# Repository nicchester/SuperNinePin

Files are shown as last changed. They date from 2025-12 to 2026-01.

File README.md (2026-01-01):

# SuperNinePin Controller Adaptor

Converts a Super Nintendo controller to an Amiga/Commodore 64 controller, using digital logic. (none of this microcontroller nonsense)

### Why do such a thing? 

It's easy to throw a microcontroller at everything, and it ocurred to me I haven't done much useful in pure digital logic with the lowest possible IC count. So this is just for the fun of doing it, and also it's quite a fitting project for a 'vintage' use case. 

---

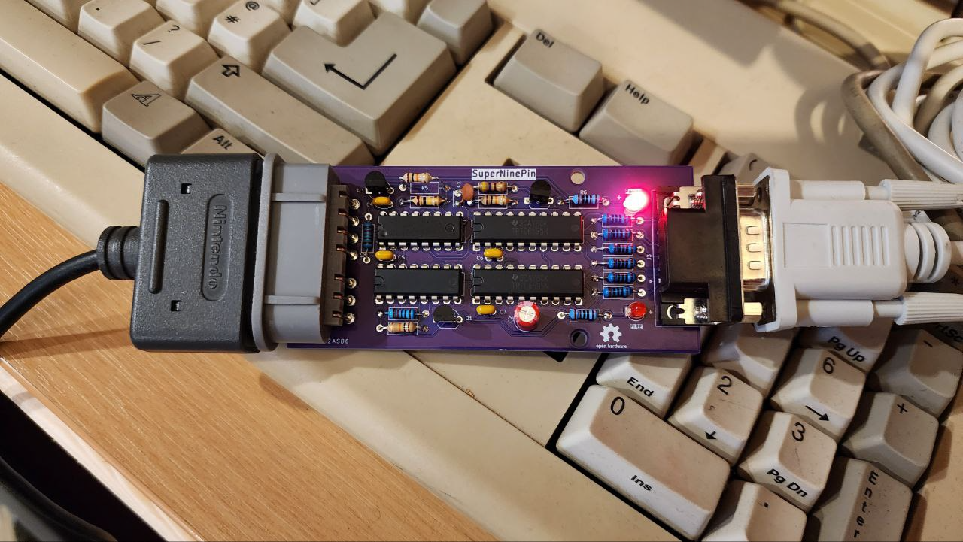
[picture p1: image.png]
The SuperNinePin hooked up to my Amiga 2000


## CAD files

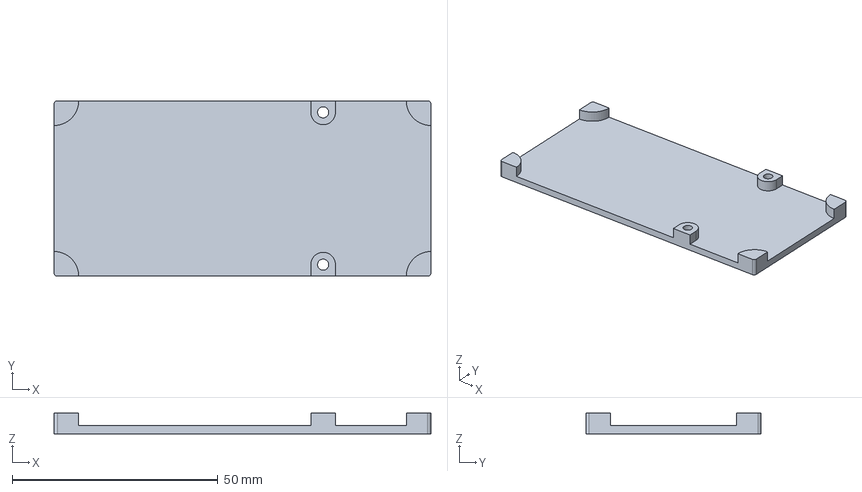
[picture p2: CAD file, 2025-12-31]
Sled/Sled.FCStd
91.6 x 42.6 x 5.00 mm

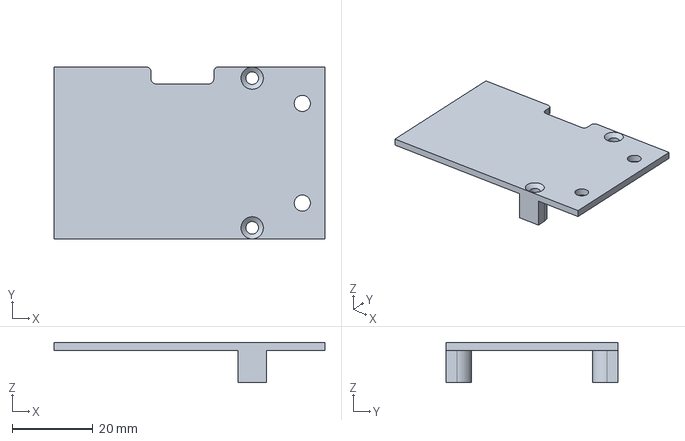
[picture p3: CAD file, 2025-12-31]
Sled/Lid.FCStd
67.0 x 42.6 x 10.0 mm

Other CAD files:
Sled/Lid.stl
Sled/Sled.stl

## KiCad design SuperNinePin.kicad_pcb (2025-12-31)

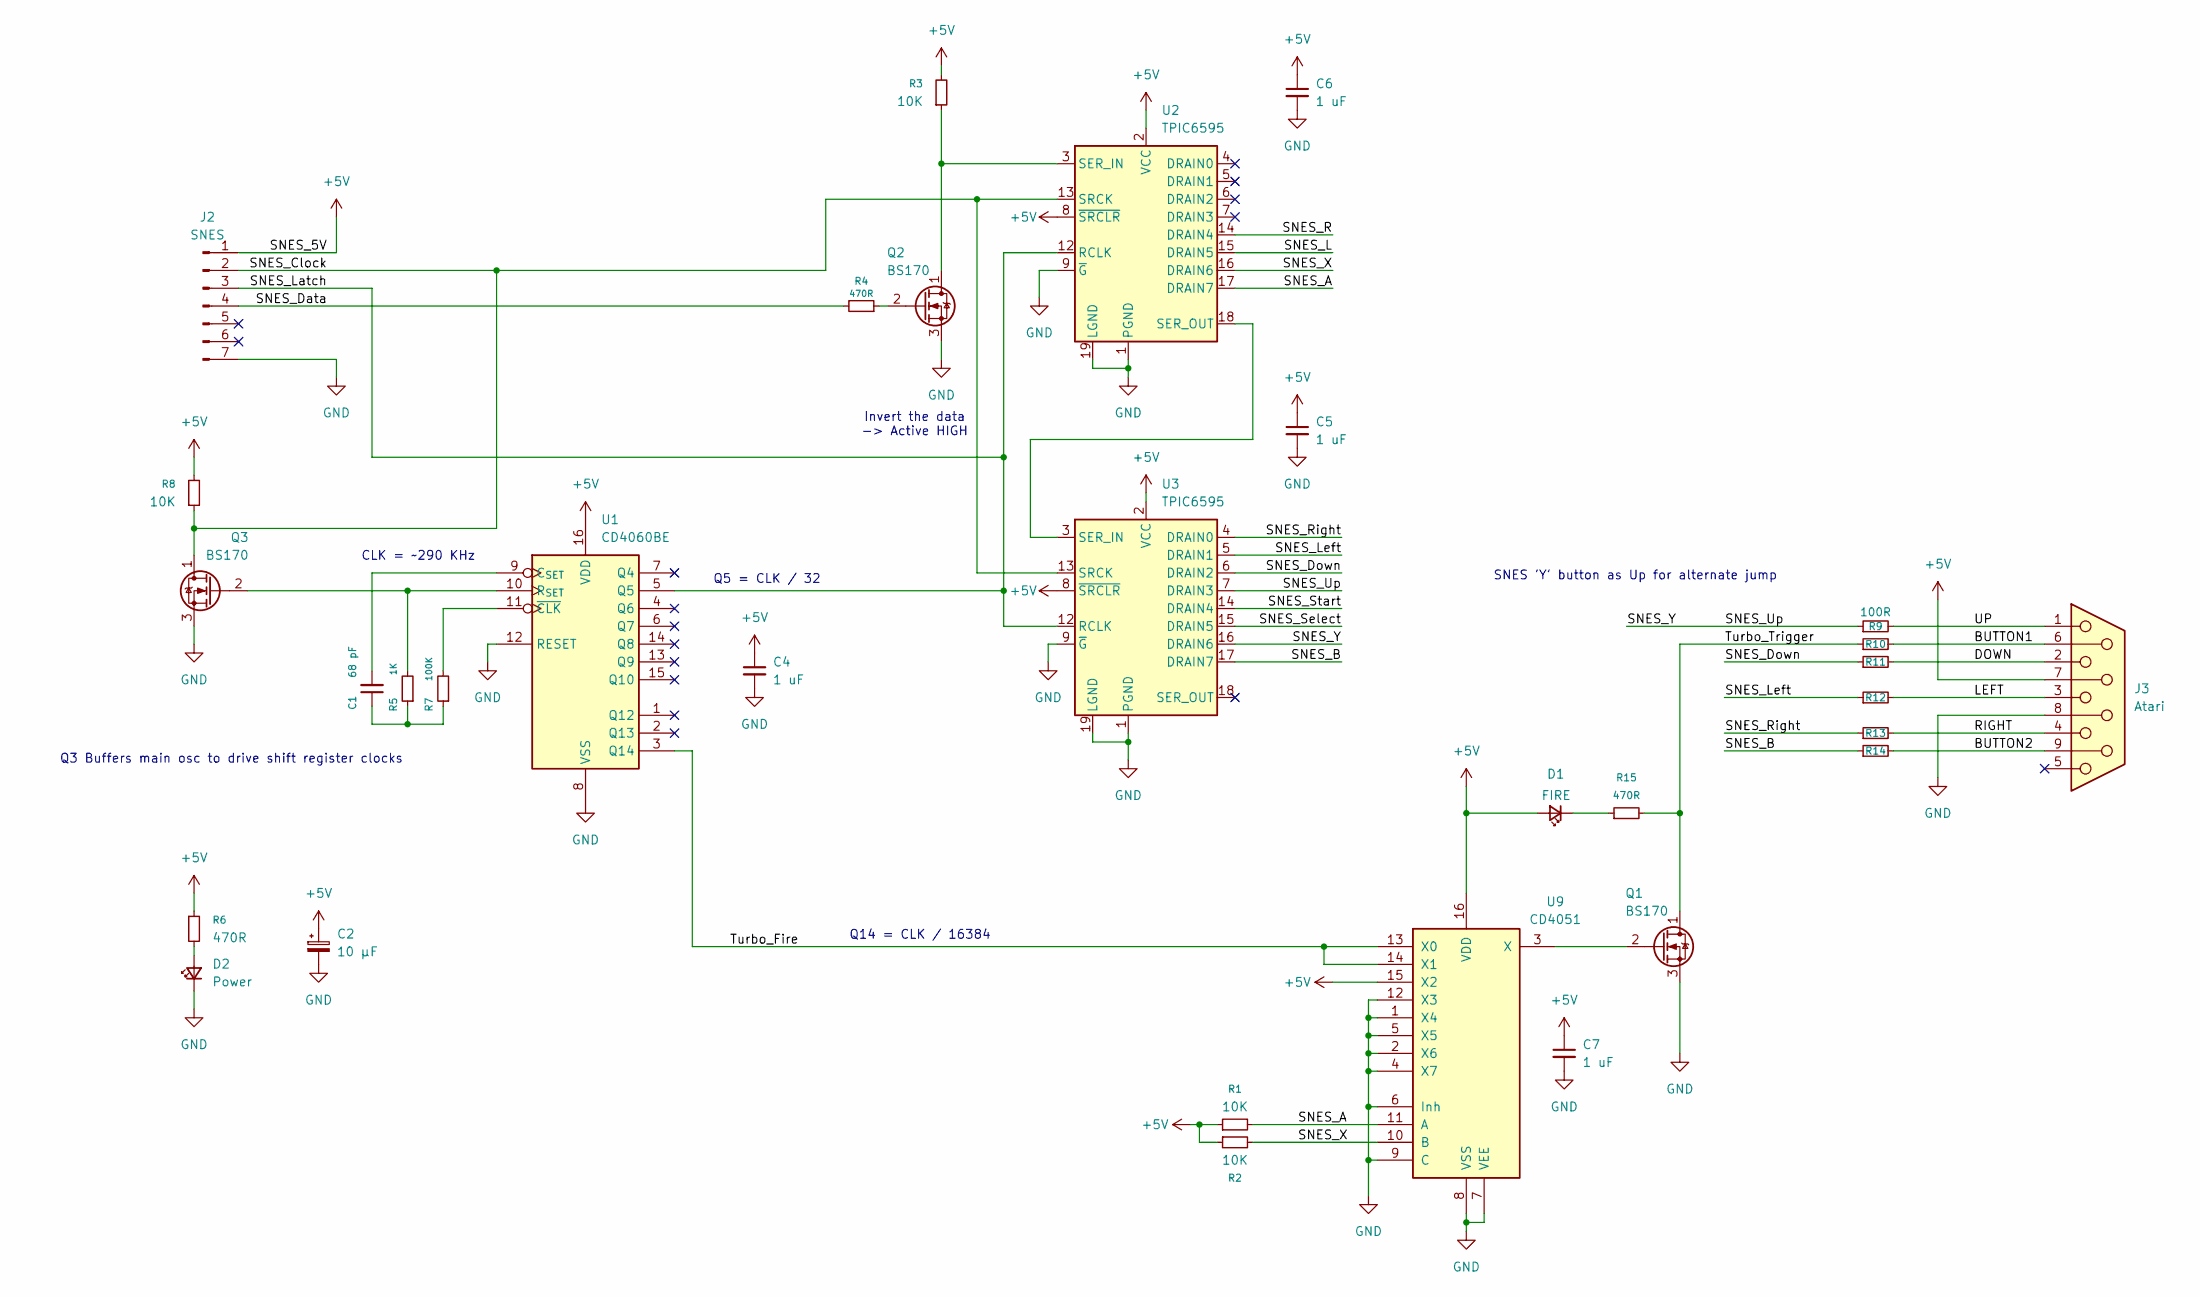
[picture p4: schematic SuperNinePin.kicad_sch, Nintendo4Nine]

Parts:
C1: 68 pF; C_Disc_D3.4mm_W2.1mm_P2.50mm
C2: 10 µF; C_Radial_D5.0mm_H5.0mm_P2.00mm
C4, C5, C6, C7: 1 uF; C_Disc_D3.0mm_W1.6mm_P2.50mm
D1: FIRE; LED_D3.0mm
D2: Power; LED_D3.0mm
J2: SNES; SNESController
J3: Atari; DSUB-9_Pins_Horizontal_P2.77x2.84mm_EdgePinOffset4.94mm_Hou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
Q1, Q2, Q3: BS170; TO-92_Inline_Wide
R1, R2, R3, R8: 10K; R_Axial_DIN0207_L6.3mm_D2.5mm_P10.16mm_Horizontal
R4, R6, R15: 470R; R_Axial_DIN0207_L6.3mm_D2.5mm_P10.16mm_Horizontal
R5: 1K; R_Axial_DIN0207_L6.3mm_D2.5mm_P10.16mm_Horizontal
R7: 100K; R_Axial_DIN0207_L6.3mm_D2.5mm_P10.16mm_Horizontal
R9, R10, R11, R12, R13, R14: 100R; R_Axial_DIN0207_L6.3mm_D2.5mm_P10.16mm_Horizontal
U1: CD4060BE; DIP-16_W7.62mm
U2, U3: TPIC6595; DIP-20_W7.62mm
U9: CD4051; DIP-16_W7.62mm

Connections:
+5V: C2.1, C4.1, C5.1, C6.1, C7.1, D1.2 (A), J2.1, J3.7, R1.1, R2.1, R3.2, R6.1, R8.2, U1.16 (VDD), U2.2 (VCC), U2.8 (~SRCLR), U3.2 (VCC), U3.8 (~SRCLR), U9.15 (X2), U9.16 (VDD)
/BUTTON1: J3.6, R10.2
/BUTTON2: J3.9, R14.2
/DOWN: J3.2, R11.2
/LEFT: J3.3, R12.2
/RIGHT: J3.4, R13.2
/SNES_A: R1.2, U2.17 (DRAIN7), U9.11 (A)
/SNES_B: R14.1, U3.17 (DRAIN7)
/SNES_Clock: J2.2, Q3.1 (D), R8.1, U2.13 (SRCK), U3.13 (SRCK)
/SNES_Data: J2.4, R4.2
/SNES_Down: R11.1, U3.6 (DRAIN2)
/SNES_L: U2.15 (DRAIN5)
/SNES_Latch: J2.3, U1.5 (Q5), U2.12 (RCLK), U3.12 (RCLK)
/SNES_Left: R12.1, U3.5 (DRAIN1)
/SNES_R: U2.14 (DRAIN4)
/SNES_Right: R13.1, U3.4 (DRAIN0)
/SNES_Select: U3.15 (DRAIN5)
/SNES_Start: U3.14 (DRAIN4)
/SNES_Up: R9.1, U3.7 (DRAIN3), U3.16 (DRAIN6)
/SNES_X: R2.2, U2.16 (DRAIN6), U9.10 (B)
/Turbo_Fire: U1.3 (Q14), U9.13 (X0), U9.14 (X1)
/Turbo_Trigger: Q1.1 (D), R10.1, R15.2
/UP: J3.1, R9.2
GND: C2.2, C4.2, C5.2, C6.2, C7.2, D2.1 (K), J2.7, J3.8, Q1.3 (S), Q2.3 (S), Q3.3 (S), U1.8 (VSS), U1.12 (RESET), U2.1 (PGND), U2.9 (~G), U2.10 (PGND), U2.11 (PGND), U2.19 (LGND), U2.20 (PGND), U3.1 (PGND), U3.9 (~G), U3.10 (PGND), U3.11 (PGND), U3.19 (LGND), U3.20 (PGND), U9.1 (X4), U9.2 (X6), U9.4 (X7), U9.5 (X5), U9.6 (Inh), U9.7 (VEE), U9.8 (VSS), U9.9 (C), U9.12 (X3)
unnamed: C1.1, R5.1, R7.1
unnamed: D1.1 (K), R15.1
unnamed: D2.2 (A), R6.2
unnamed: Q1.2 (G), U9.3 (X)
unnamed: Q2.1 (D), R3.1, U2.3 (SER_IN)
unnamed: Q2.2 (G), R4.1
unnamed: Q3.2 (G), R5.2, U1.10 (R_{SET})
unnamed: C1.2, U1.9 (C_{SET})
unnamed: R7.2, U1.11 (~CLK)
unnamed: U2.18 (SER_OUT), U3.3 (SER_IN)

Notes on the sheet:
Q14 = CLK / 16384
SNES 'Y' button as Up for alternate jump
Invert the data -> Active HIGH
Q5 = CLK / 32
Q3 Buffers main osc to drive shift register clocks
CLK = ~290 KHz

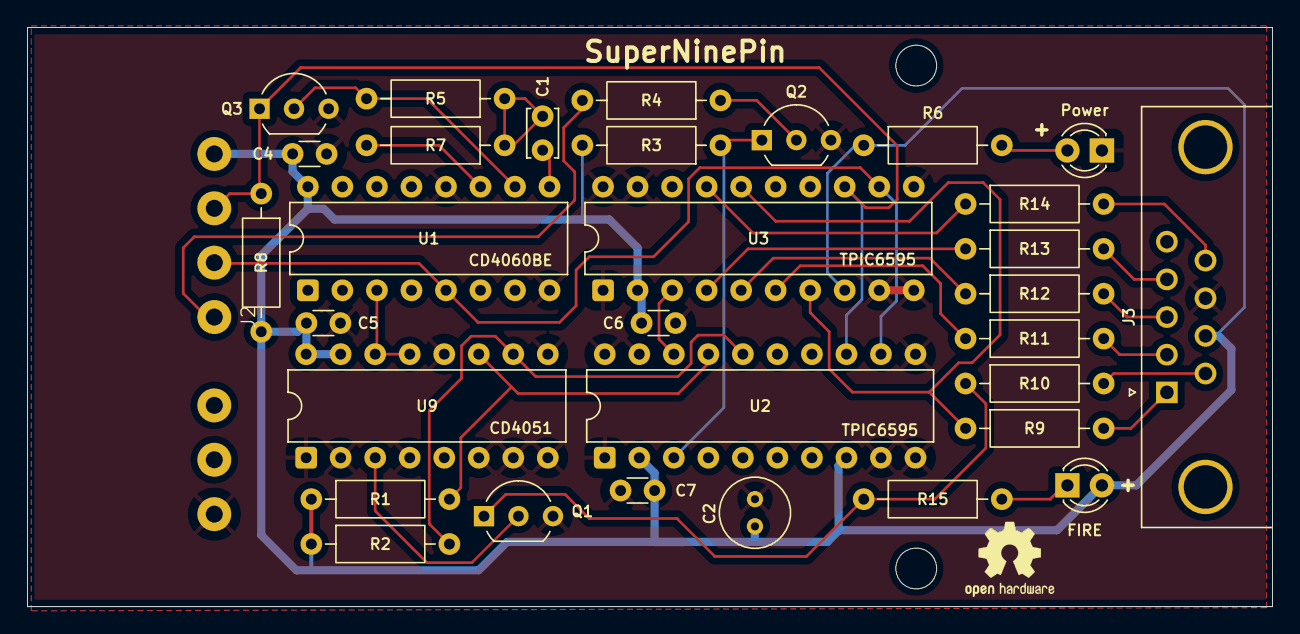
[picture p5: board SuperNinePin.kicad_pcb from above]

Board: 2 copper layers, 91.6 x 42.6 mm, 32 parts (0 on the bottom side), 30 nets.

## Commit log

2025-12-03 Adds kicad & simulation project files
    [SuperNinePin.kicad_pcb, SuperNinePin.kicad_sch]
2025-12-03 Swaps 555 + 4040 for 4060, swaps 74HC595 for TPIC6595
    [SuperNinePin.kicad_sch]
2025-12-31 Adds gerbers, crude enclosure
    [Lid.FCStd, Lid.stl, Sled.FCStd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]
